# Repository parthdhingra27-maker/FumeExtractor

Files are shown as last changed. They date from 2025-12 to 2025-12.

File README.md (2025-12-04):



<h1 align="center">FumeExtractor: A Custom DIY Fume Extractor</h1>
<p align="center">Project Files:</p>

<p align="center">
  <a href="https://cad.onshape.com/documents/5f3d41ebaa1ff2dac727490e/w/8e68a1356115bec1a9412777/e/b809de6d9b36ae64cb4acad5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">Onshape CAD Files</a> •
  <a href="https://docs.google.com/spreadsheets/d/1JyTsFHx3Wv45ex6Yl0bQmdz0n9tQV2E78bBc04w5R7Y/edit?usp=sharing">Bill of Materials</a> •
  <a href="https://blueprint.hackclub.com/projects/2891">Blueprint Journal</a>
</p>

I built this to learn PCB design and to create a custom, cool-looking fume extractor to suck in solder fumes.

## Features
- Removable Filter: The filter is easily removable by sliding it out from the top
- High CFM: One Arctic Pro fan provides 50 CFM, which helps remove a lot of the fumes while soldering
- Low Cost: The whole extractor with a custom PCB and screen costs around $50, which is similar to most extractors on Amazon
- Tiltable: The angle of the extractor can be changed as needed
- Fully 3D Printable: All the physical parts other than the electronics are 3D printed, making it easy to make
- The speed of the fan is controlled using a knob connected to an Arduino Nano
- There is an OLED screen to show the fan speed

## Design and CAD

The Onshape link can be found at the top of the README.

The filter slides in from the top, and then the fan comes in behind it and screws into heat-sink inserts. Then the lid in the back closes the extractor using embedded magnets in the plastic.



This is the back view:



This is the underside:



The sides pivot using a screw on the outside that screws into a heat-sunk insert attached to the main extractor:



The whole project uses M3 hardware and heat-sunk inserts.

## PCB and Schematics:

This is the schematic for the custom PCB. The board is powered from a bench power supply. The screw terminals go to the fan pins, the rocker switch, the knob to control fan speed, and the power from the bench power supply. There are also header pins for the OLED screen.
There's also a buck convertor to convert the 12v to 5v to power the Arduino Nano.







## Bill of Materials
These are the components needed. The prices and links can be found here:  <a href="https://docs.google.com/spreadsheets/d/1jZwi7d67DiPdZLEvy5LfeC6HyOPPZ9pO3xaRMX1j6oo/edit?usp=sharing">Bill of Materials Google Sheets</a>

- 1 x PCB
- 1 x Arduino Nano
- 1 x Set of M3 Heat Sunk Inserts
- 1 x Set of M3 Hardware
- 1 x Arctic Pro 120mm Fan
- 1 x Speed Control Knob
- 1 x Toggle Switch On Off
- 1 x Set of 20AWG Wire
- 1 x XT60 to Wire Connector for Bench Power Supply to PCB
- 1 x 1.3in OLED Screen
- 1 x Set of Rubber Feet
- 1 x Set of KF301 Screw Terminals
- 1 x 10k Resistor
- 1 x 1x4 2.54 Pin Header
- 1 x LM2596 Buck Convertor
- 1 x Activiated Carbon Filter 13cm x 13cm x 1cm
- 1 x JST-XH 4P
- 3 x 2 Wire Screw Terminals
- 15 x 1.5mm 20mm Long Metal Rod

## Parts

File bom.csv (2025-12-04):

Part Name | Link | Vendor | Qty | Price Per Unit | Total Item Price | Item Notes
Toggle On Off Switch | https://www.aliexpress.us/item/3256806092929837.html?curPageLogUid=mY2dHjlF89ns | Aliexpress | 1 | $2.14 | $2.14 | No Lamp Option
Arctic Pro Fan | https://www.amazon.com/ARCTIC-P12-Pro-Powerful-600-3000/dp/B0DJDC74BP | Amazon | 1 | $8.49 | $8.49 | Same price as Aliexpress ones but higher CFM
Speed Control Knob | https://www.aliexpress.us/item/3256806841285775.html?curPageLogUid=h0o4hARSVcNu | Aliexpress | 1 | $2.05 | $2.05 | 10k OHM
Wire | https://www.aliexpress.us/item/3256807223924930.html?curPageLogUid=vZU5MKCxRj3q | Aliexpress | 1 | $2.21 | $2.21 | RB 3M
XT60 Connector | https://www.aliexpress.us/item/3256807190011486.html | Aliexpress | 1 | $1.88 | $1.88 | Female
M3 Heat Set Inserts | https://www.aliexpress.us/item/3256803396040989.html?curPageLogUid=HrDCkrxltSyF | Aliexpress | 1 | $1.89 | $1.89 | M3 OD 4.2mm Length 3mm
OLED Screen | https://www.aliexpress.us/item/3256807264700302.html?curPageLogUid=vd8nPepHN2uf | Aliexpress | 1 | $2.70 | $2.70 | 4P White
Arduino Nano | https://www.aliexpress.us/item/3256807121866025.html?curPageLogUid=9w3EKhnK5ofq | Aliexpress | 1 | $4.24 | $4.24 | Type-C USB Welding
PCB | Screenshot | JCLPCB | 1 | $7.12 | $7.12
Rubber Feet | https://www.aliexpress.us/item/3256804119199524.html?curPageLogUid=H6m8WbO7FlN6 | Aliexpress | 1 | $2.35 | $2.35
4 Wire Screw Terminal | https://www.aliexpress.us/item/3256806456550715.html?curPageLogUid=EMONetS7J3tL | Aliexpress | 1 | $1.85 | $1.85 | 4P Blue
10k Resistor | https://www.aliexpress.us/item/3256806808241885.html?curPageLogUid=eBK49bHIjc2G | Aliexpress | 1 | $3.86 | $3.86 | Need 10k, 100
Activated Carbon Filters | https://www.aliexpress.us/item/3256808818476787.html?curPageLogUid=aKtzcpalYMy9 | Aliexpress | 1 | $5.17 | $5.17
2,3,4 Screw Terminals | https://www.aliexpress.us/item/3256809181564120.html?curPageLogUid=2P0hudLQJ3kA | Aliexpress | 1 | $3.92 | $3.92 | Blue
1x4 Pin 2.54 Header | https://www.aliexpress.us/item/2255800801798474.html?curPageLogUid=qweLxaOrtZxf | Aliexpress | 1 | $1.58 | $1.58
Buck Convertor | https://www.aliexpress.us/item/3256807314089934.html | Aliexpress | 1 | $1.60 | $1.60
Parts Total | $51.45
Shipping Total | $0.00
Subtotal | $51.45
Tax (Virginia 4.5%) | $2.32
Project Total | $53.77

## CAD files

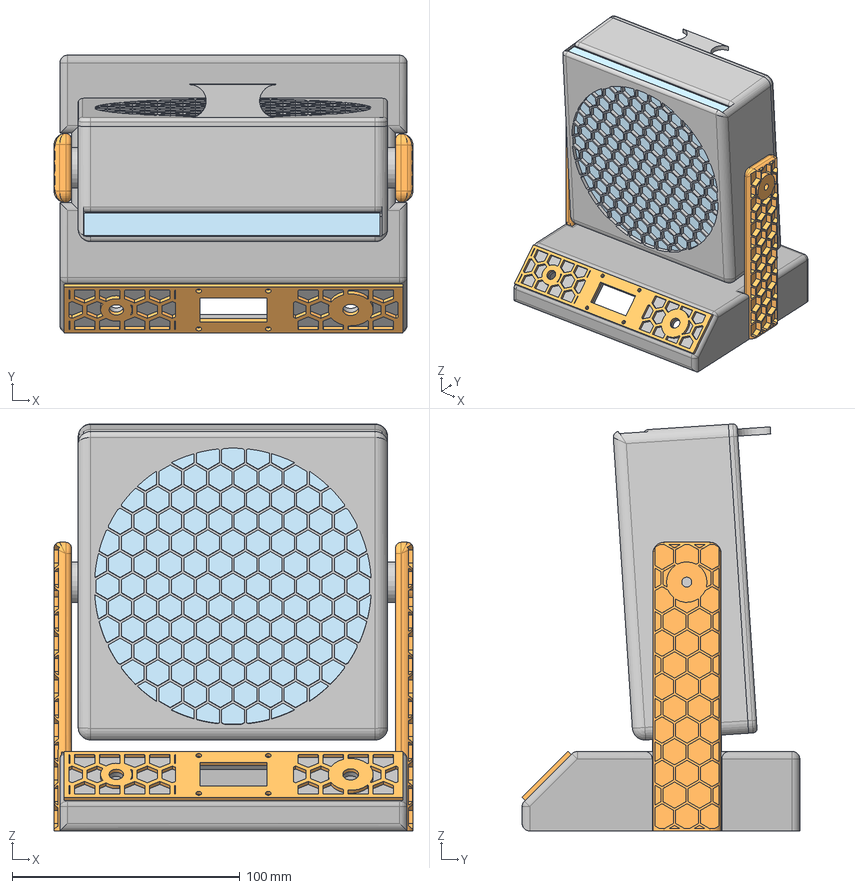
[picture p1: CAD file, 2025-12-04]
CAD/Main Assembly (1).step
157.5 x 121.9 x 178.6 mm
120mm Fan
HEX
Right Beam
BACK LID
Filter Model
BASE
Left Beam

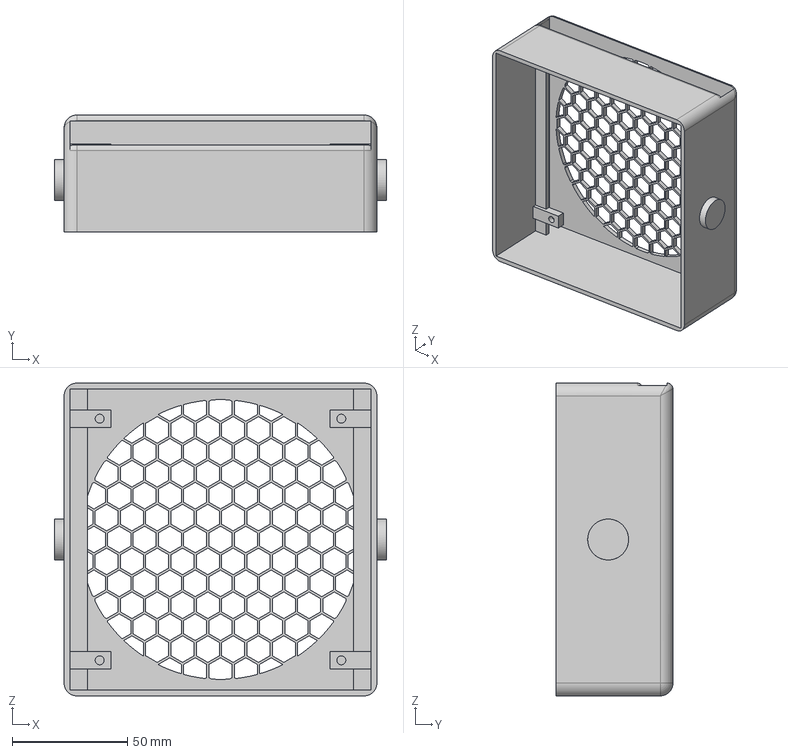
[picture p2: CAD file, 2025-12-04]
CAD/Part Studio 1 - BOX.step
144.3 x 50.8 x 135.9 mm

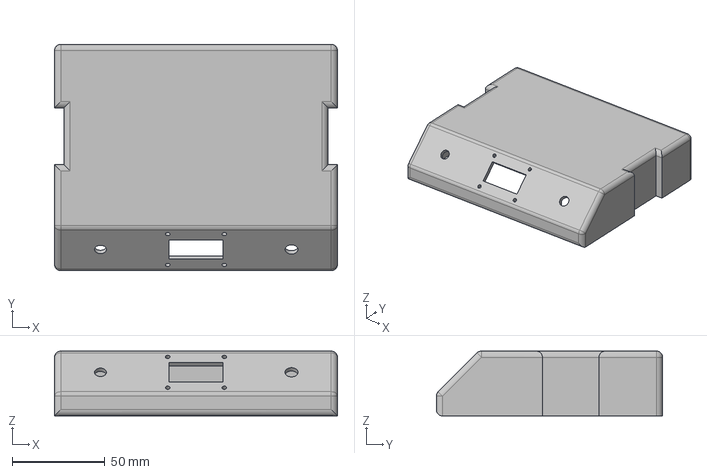
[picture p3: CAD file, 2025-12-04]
CAD/Part Studio 1 - BASE.step
152.4 x 121.9 x 34.9 mm

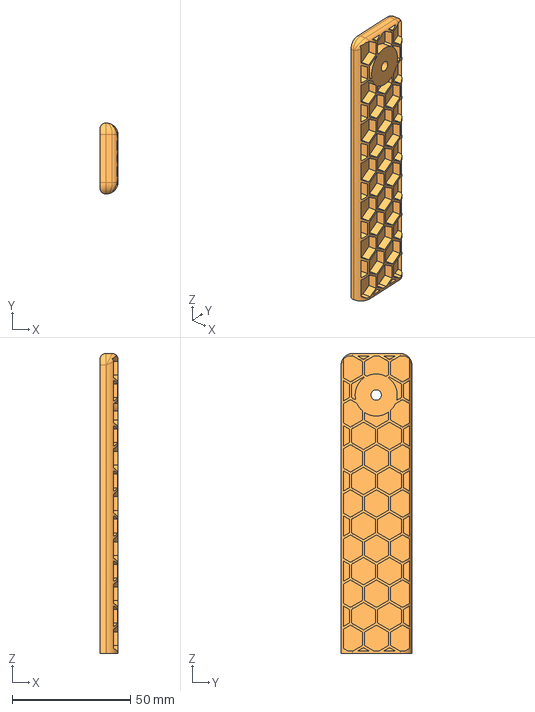
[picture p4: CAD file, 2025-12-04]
CAD/Part Studio 1 - Right Beam.step
7.62 x 30.0 x 126.7 mm

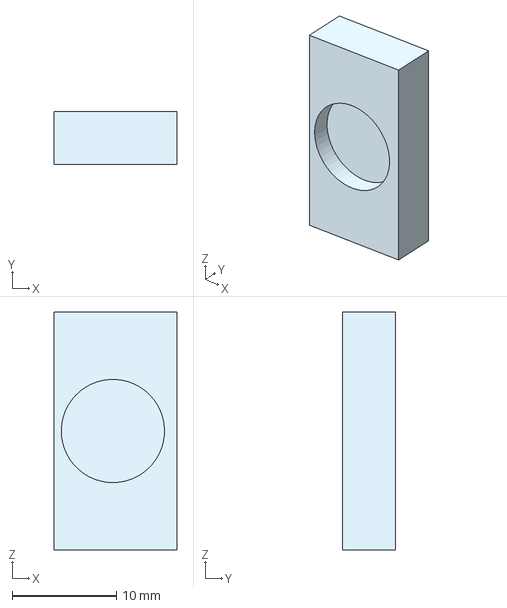
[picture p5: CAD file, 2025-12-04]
CAD/Part Studio 1 - Magnet1.step
11.8 x 5.08 x 22.8 mm

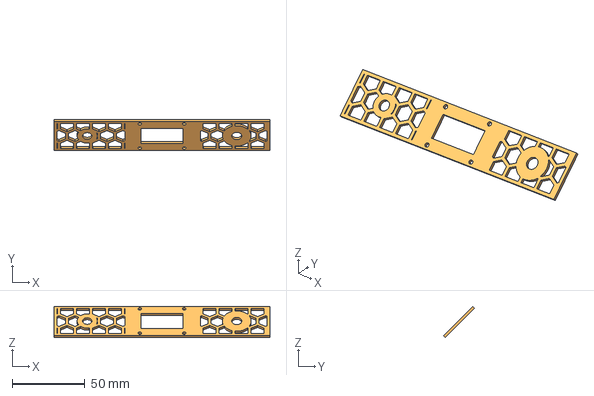
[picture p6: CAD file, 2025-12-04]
CAD/Part Studio 1 - HEX.step
148.6 x 21.5 x 21.5 mm

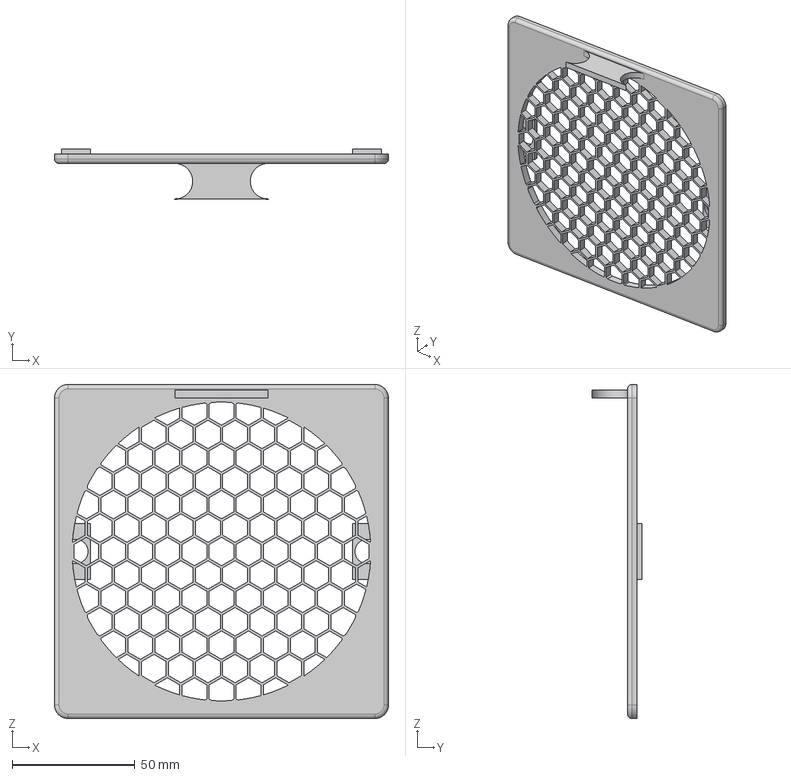
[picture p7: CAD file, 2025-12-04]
CAD/Part Studio 1 - BACK LID.step
135.9 x 20.4 x 135.9 mm

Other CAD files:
CAD/Part Studio 1 - Left Beam.step
CAD/Part Studio 1 - Magnet2.step

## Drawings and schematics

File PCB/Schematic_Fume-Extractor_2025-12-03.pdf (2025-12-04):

A | A

1

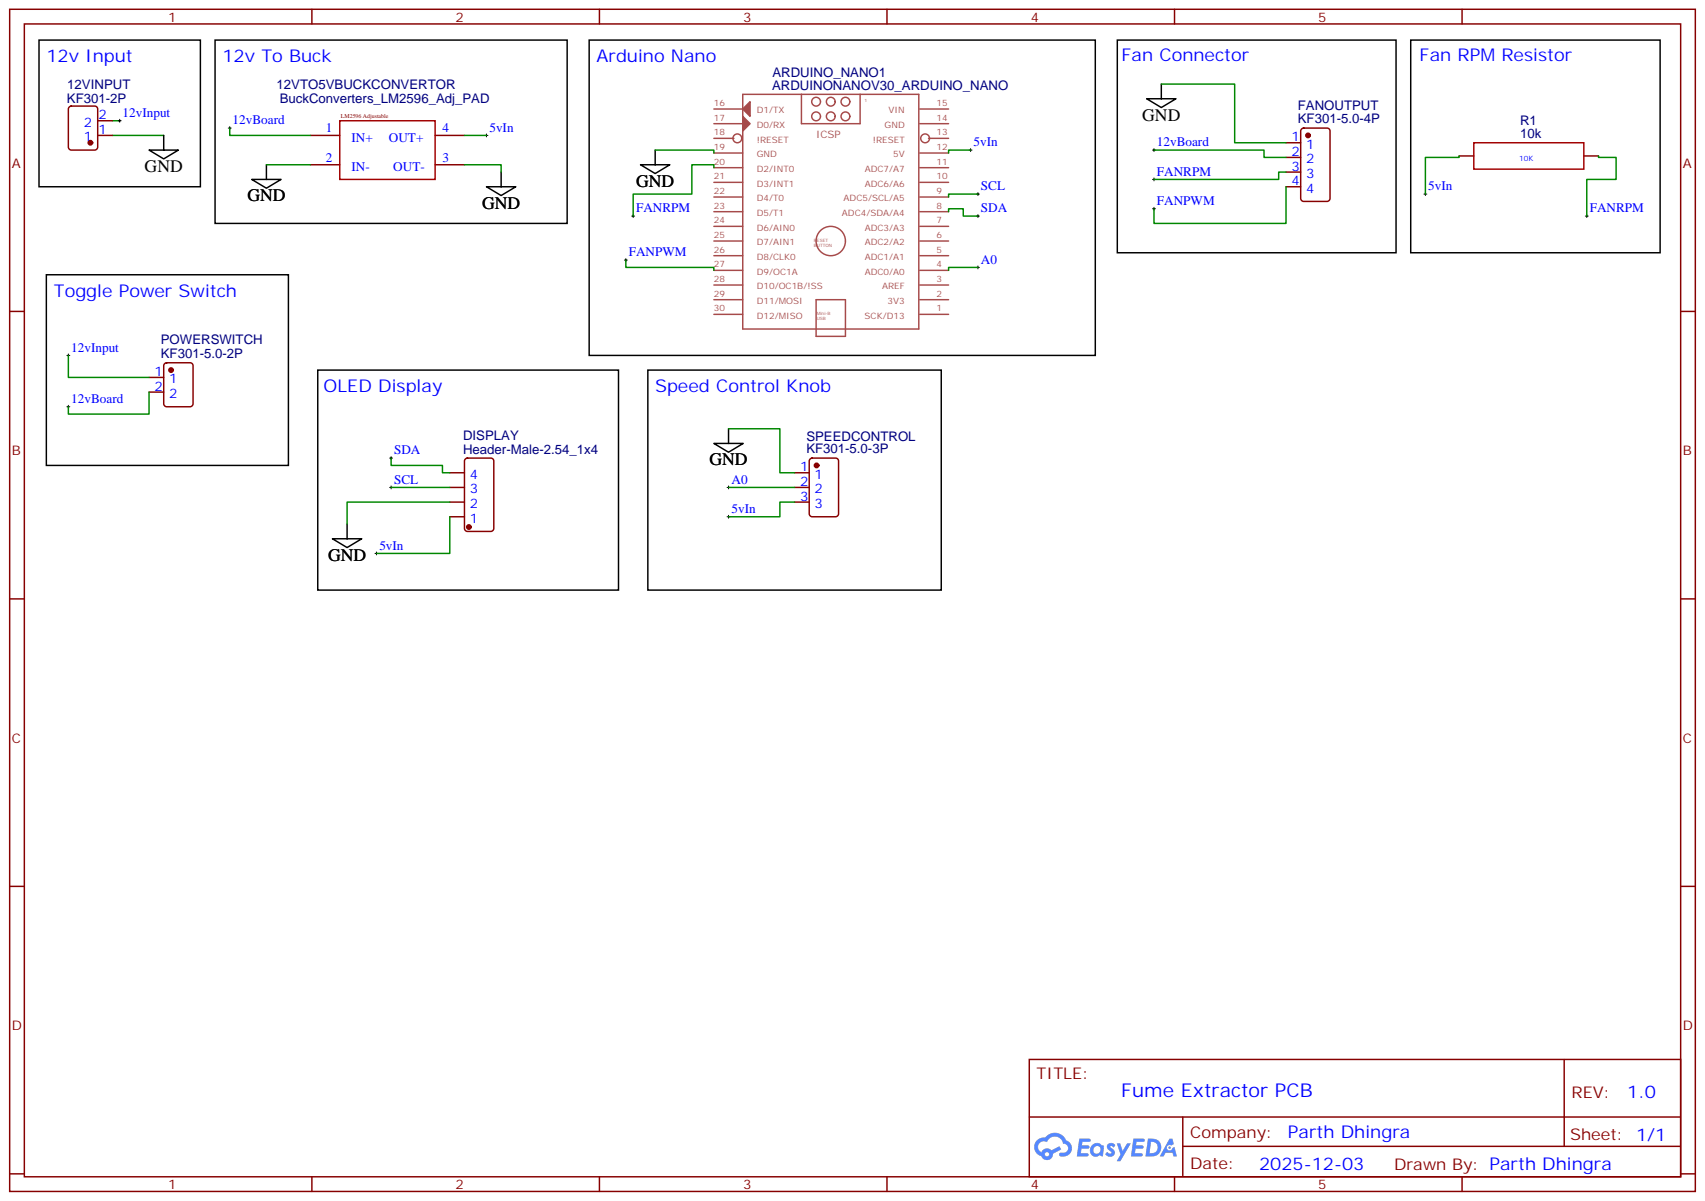
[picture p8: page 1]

Drawn By: Parth Dhingra

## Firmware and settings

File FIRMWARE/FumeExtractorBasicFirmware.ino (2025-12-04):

#include <Wire.h>
#include <Adafruit_GFX.h>
#include <Adafruit_SSD1306.h>

#define SCREEN_WIDTH 128
#define SCREEN_HEIGHT 64
Adafruit_SSD1306 display(SCREEN_WIDTH, SCREEN_HEIGHT, &Wire, -1);

// Pin definitions
const int knobPin = A0;     // Speed control knob
const int pwmPin = 9;       // Fan PWM control
const int rpmPin = 2;       // Fan RPM signal (interrupt)

// Variables for RPM measurement
volatile unsigned long pulseCount = 0;
unsigned long lastRPMTime = 0;
int currentRPM = 0;

// Interrupt handler for RPM
void rpmISR() {
  pulseCount++;
}

void setup() {
  pinMode(knobPin, INPUT);
  pinMode(pwmPin, OUTPUT);
  pinMode(rpmPin, INPUT_PULLUP);

  // Attach interrupt to RPM pin
  attachInterrupt(digitalPinToInterrupt(rpmPin), rpmISR, FALLING);

  // Setup OLED
  if (!display.begin(SSD1306_SWITCHCAPVCC, 0x3C)) {
    for (;;);  // hang if display not found
  }
  display.clearDisplay();
  display.setTextColor(WHITE);
  display.setTextSize(1);

  // Set PWM frequency for pin 9 → Fast PWM (~31kHz ideal for PC fans)
  TCCR1B = (TCCR1B & 0b11111000) | 0x01; 
}

void loop() {
  // Read knob value
  int knobValue = analogRead(knobPin);
  int pwmValue = map(knobValue, 0, 1023, 0, 255);

  // Send PWM to fan
  analogWrite(pwmPin, pwmValue);

  // Update RPM every 1 second
  if (millis() - lastRPMTime >= 1000) {
    noInterrupts();
    unsigned long pulses = pulseCount;
    pulseCount = 0;
    interrupts();

    currentRPM = pulses * 30;  // 2 pulses/rev → *30 for RPM

    lastRPMTime = millis();
  }

  // OLED Display
  display.clearDisplay();
  display.setCursor(0, 0);
  display.println("FUME EXTRACTOR");
  display.println("--------------------");

  display.print("PWM: ");
  display.print(map(pwmValue, 0, 255, 0, 100));
  display.println("%");

  display.print("RPM: ");
  display.println(currentRPM);

  display.display();

  delay(50);
}
